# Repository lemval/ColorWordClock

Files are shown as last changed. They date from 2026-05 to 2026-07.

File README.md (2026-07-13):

# Dutch Color clock

Hi,

This is a personal project with lots of effort to get it up and running.
If you have build a clock, please give a little credit to this project. 
This will be greatly appreciated via [Paypal](https://www.paypal.me/valkyer).

The layout of the clock is Dutch! However, it will be pretty easy to create the clock in any language as long as it fits in text. Design your clockface first before proceeding.

## The clock

This is the first version I've build. It uses an aluminium U-frame to hold all layers together. Wood (milled) is easier to work with. It also still uses a DC power connector. Later models are equiped with a USB C connector.

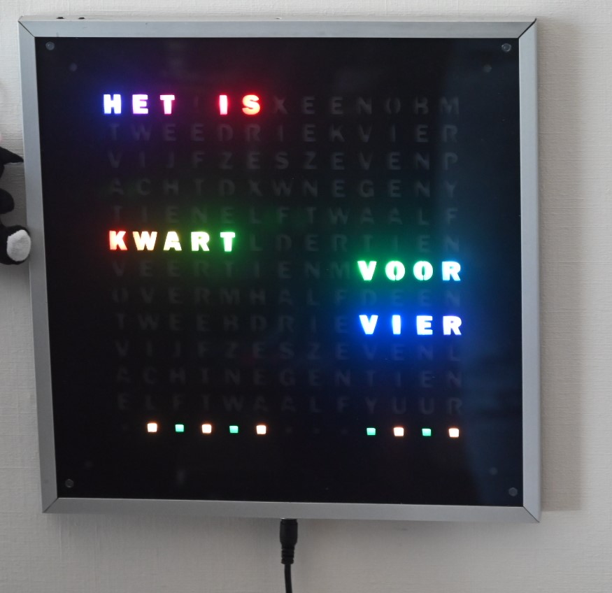
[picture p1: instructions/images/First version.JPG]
First version The first clock


All configurations can be done via the website on the clock.

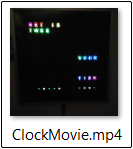
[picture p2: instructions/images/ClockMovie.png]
Check the movie
!

### Faces

1. Warm (text is warm white)
1. Custom (text is a custom color)
1. Rainbow (text uses a rainbow spectrum as seen in the picture above)
1. Animate (same, but slowly shifting)
1. ColorWord (each word another color)
1. ColorChar (each character another color)

### Ticking

The ticking is in a color of your own choice, lightning each corners per 15 seconds, with the following options:
1. Switched off
1. Blink each second
1. Burning solid
1. Fade from solid to off

### Transitions

1. None (no transition)
1. Random (each minute a random pick of transition)
1. Animate (each minute a random FastLED pattern)
1. Flow down (characters fall down...)
1. Fade (text fades out and in)
1. Swipe (remove and reappear by swipe from bottom to top and back)
1. Scanner (same, but starting from right)
1. Spiral (FastLED spiral)
1. Fire (FastLED fire)
1. Rings (FastLED rings)
1. Wave (FastLED waves)
1. Mill (FastLED rotating like a mill)

You have the option to set the duration and animation speed.

### Status bar

The status bar is by default the date in binary. You have the option for some fixed patterns or use the 13 LEDs as status fields from Home Assistant. I tend to like having the date displayed.

## Hardware

Besides some small stuff, you need the following as mentioned below. Costs will be between 50 and 100 euro on material.

Instructions for building the clock are found in the [instruction folder](instructions/Readme.md).

### Board

The clock can fit a model esp32-c6 devkit, which is easy to use and to connect, although the devkit is larger in size.
 
You need at least a 4MB card, however it has only be tested on a 8MB and 16MB card. If you skip OTA capability (you then have to disassemble the clock to update!) you can use a 2MB card.

### Light sensor

Use a model 5516 in combination with a 4K7 resistor.

### LED strip
You need 173 leds (13 x 13 + 4) on a 60D RGB strip, totaling to 3 meter. Use model HD107HD/APA107 (60 leds per meter) or alike, but make sure you can cut each LED individually. Using another model means also changing led_array.h (at FastLED.addLeds).

FastLED supports the SK6812 WWA version for warm/cold white. The upcoming release uses SK6812WWA (alias to SK6812Controller). See [FastLED/FastLED#2347](https://github.com/FastLED/FastLED/pull/2347). I currently have no knowledge if the software will run nicely using such strip.

### Power adapter
A 5 volt power adapter (preferrably USB C but other connectors work) able to deliver at least 30W (6A) but preferrably 45W (9A).

### Power connector

The design is configured for a 20 x 14 x 6.5 mm inlet. See for example [here](https://nl.aliexpress.com/item/1005009400273099.html).

### Materials

Note: you need a laser cutter or have access to one!
All layers should measure at least 30cm x 30cm square

* Ground layer: 6 mm basewood (or alike)
* LED layer: 2 mm MDF
* Control layer: 6 mm MDF (or basewood)
* Diffusion layer: A4 size tracing paper
* Text layer: 0.5mm Lasersheet
* Front layer: 3 mm Tinted grey transparent polycarbonate (or alike)
* Frame: Your choice

I created frames from wood (milled) and alu (U-profile). Be creative.
Be careful to not glue the front and text layer. It will show.

## Software

Create a `settings.h` based on `settings.h.template`. You can show a 'happy birthday' on given dates as transition.

Create a `platformio-local.ini` in the same manner. This allows for using your own password for OTA updates.

Change to your board size in `platformio.ini` by using one of the preconfigured board size config files (set to 16MB standard).

Compile, run and upload using Visual Studio Code with PlatformIO as plugin.

When started, connect to Wifi network 'Clock' and navigate to 192.168.4.1 to configure the Clock for first use. After that, reconnect to a regular Wifi network and open the browser on the assigned IP address.

Once your clock is closed up (assembled) you can only update via OTA.

## Pin layout

* 04 Settings - select (connect other side to GND)
* 05 Settings - next (connect other side to GND)
* 06 Light sensor (3.3V - LDR - SENSOR - 4K7 - GND)
* 19 LED strip - clock
* 20 LED strip - data

## Control

The settings buttons will allow you to configure the clock on a basic level. To configure on a finer level, just open the browser to the clock (not very reactive, since the clock is working on showing you the time and transitions) or use the Home Assistant integration (just configure MQTT via the browser, run a MQTT server and let Home Assistant read from that server).

### Configuration

Press SELECT once to enter settings mode. Press NEXT to cycle through the options of the setting or press SELECT again for the next setting or for closing the settings mode.

Settings are:
1. Change clockface
1. Change transition
1. Activate or disable light sensor
1. Activate or disable seconds
1. Set transition time 

Active = white, disabled = blue.

### Reset

Press NEXT, followed by SELECT. Lower left LED will turn green. Keep pressed and the LED will turn orange. When it turns red after 5 seconds, the clock and network will reset. You have to reconnect to the AP 'Clock' after that.

### Startup

At startup, at the right bottom, red, blue and green will show. As soon as the wifi is connected the red will disappear. As soon as Home Assistant integration and the configuation server is started, blue will switch off. If the clock as been fully initialized, green will follow.

So, when all three colors keep on showing, either the wifi connection fails or the wifi connnection is not configured. The clock should then act as an access point named 'Clock'. Connect to the network and open a browser to the clock its IP address (likely: 192.168.4.1) and configure it.

## Attributes

The following components or libraries are used:

* [WiFiManager by tzapu](https://github.com/tzapu/WiFiManager) (MIT license)
* [home-assistant-integration by dawidchyrzynski](https://github.com/dawidchyrzynski/arduino-home-assistant) (AGPL-3.0 license)
* [NTPClient by arduino-libraries](https://github.com/arduino-libraries/NTPClient) (MIT license)
* [TimeZone by jchristensen](https://github.com/JChristensen/Timezone) (GPL-3.0 license)
* [GoogleTest by Google](https://github.com/google/googletest) (BSD-3-Clause license)
* [FastLED by fastled](https://github.com/FastLED/FastLED) (MIT license)
* [Visual Studio Code](https://code.visualstudio.com/) for coding
* [PlatformIO](https://platformio.org/) for ESP support
* [OpenSCAD](https://openscad.org/) for designing the clock layout
* [LaserGRBL](https://lasergrbl.com/) for burning the layout
* [Cliche](https://www.1001fonts.com/cliche-font.html) for the clock text

## Releases

* Jun 18, 2026 - Version 1.1.0 - Public release

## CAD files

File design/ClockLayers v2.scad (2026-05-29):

// Copyright (c) 2026 - Lemval

clockSize = 300;     // How large is the clock (square)
step = 16.6667;      // The length between each LED center
dotsPerLine = 13;    // Number of LEDs per line 
dotMargin = 27;      // Distance dots from side
lineSize = 12;       // Width of the LED strip
dotSize = 5;         // Size of the LED dot
leader = 12.5;       // Space left and right for soldering
screwSize = 3.25;    // M3 with some slack
resCircle = 15;      // Smoothen circles 
resText = 50;        // Smoothen text
screwOffset = 14.5;  // Location of the corner screws
deviceWidth = 54;    // Width of the ESP
deviceHeight = 32;   // Height of the ESP
deviceThickness = 7; // Thickness of the ESP

// Glueing magnets to the front plate requires non-invasive glue!
// magnetSize = 5.1;
// magnetOffset = 20;

// If you use another layout (other language), make sure you work the code.
letters="HET!ISXEENOBMTWEEDRIEKVIERVIJFZESZEVENPACHTDXWNEGENYTIENELFTWAALFKWARTLDERTIENVEERTIENMVOOROVERMHALFDEENTWEEBDRIEVIERVIJFZESZEVENLACHTNEGENTIENELFTWAALFYUUR▪▪▪▪▪▪▪▪▪▪▪▪▪";
fontSize=12;
fontName="Cliche:style=regular";

// There are different layers to cut. Generate or use existing ones.
// The power line uses a USB C socket. Change the model for other sockets.
// Speed/power/passes are based on a 20W diode laser.

// printGroundLayer();   // Basewood 6 mm - 300mm/m, 100%, 2 passes
// printEngraveLayer();  // On ground layer - 3000mm/m, 20%, 1 pass
// printLedStripLayer(); // MDF 2 mm - 400mm/m, 100%, 1 pass
// printControlLayer();  // MDF 6 mm - 300mm/m, 100%, 3 passes
// printTextLayer();     // Lasersheet 0.5mm - 600mm/m, 90%, 1 pass

module printGroundLayer() {
    difference() {
        square(clockSize);
        Screws();
    }
}

module printEngraveLayer() {
    // This layer can be used for aligning LEDs on LED layer
    width=0.1;
    // Center line
    translate([clockSize/2, clockSize/2, 0]) square([width, clockSize], center=true);
    // Dot lines, left vertical
    translate([dotMargin, clockSize/2, 0]) square([width, clockSize], center=true);
    // Dot lines, right vertical
    translate([clockSize-dotMargin, clockSize/2, 0]) square([width, clockSize], center=true);
    // Dot lines, top horizontal
    translate([clockSize/2, clockSize-dotMargin, 0]) square([clockSize, width], center=true);
    // Dot lines, bottom horizontal
    translate([clockSize/2, dotMargin, 0]) square([clockSize, width], center=true);
    translate([dotMargin+5, 12, 0]) text("(c) 2026 Lemval", font=fontName, size=6, $fn=50);      
}

module printLedStripLayer() {
    // Carved for strips and wiring
    difference() {
        square(clockSize);
        union() {
            for(idx = [0 : 1 : dotsPerLine-1]) 
                StripLed(idx, false);
            Screws();
            Device();
            DotWires();
            PowerConnector();
        }
    }
}

module printControlLayer() {
    // Carved for device and light boxes
    // mirror([180,0,0]) 
    difference() {
        square(clockSize);
        union() {
            // Add the text squares
            for(idx = [0 : 1 : dotsPerLine-1]) 
                Text(idx, true);
            Screws();
            Device();
            LightSensor();
            Switches();
            PowerInlet();
            Dots(true);   
            // Magnets(); 
        }
    }
}

module printTextLayer() {
    // Carved for text
    difference() {
        square(clockSize);
        union() {
             Dots(false);     
             for(idx = [0 : 1 : dotsPerLine-1]) Text(idx, false);
            // Magnets(); 
            // Bolts();
        }
    }
}

module Device() {
    translate([44, clockSize-39, 0]) 
        square([deviceWidth+20,deviceHeight]);
}

module LightSensor() {
    // Space on top. Drill when needed for wires
    translate([clockSize/2, clockSize-1, 0]) 
        square([4.2,2], true);
    // Vertical portal
    translate([clockSize/2, clockSize-18, 0]) 
        square([4,20], true);
    // Horizontal portal
    translate([45+deviceWidth, clockSize-31, 0]) 
        square([clockSize/2-45-deviceWidth+2,4]);
}

module PowerConnector() {
    // Conduit
    translate([clockSize/2, 15]) square([10, 20], true);
    // Extra wire space
    translate([clockSize/2, 18]) square([18, 9], true);
}

module PowerInlet() {
    translate([clockSize/2-10, 0]) square([20, 2.5]);
    translate([clockSize/2, 10]) square([10, 20], true);
}

module Switches() {
    // Small holes should be drilled from the side.
    offset = 17;
    // Switch 1
    translate([offset, clockSize-15,0]) square([7,10], false);
    // Switch 2
    translate([offset+13, clockSize-15,0]) square([7,10], false);
    // Switch wire
    translate([offset, clockSize-17,0]) square([28,3], false);
}

module StripLed(row, showDots) {
    length = leader + dotsPerLine * step;
    height = dotsPerLine * step - (lineSize/2);
    startX = (clockSize - length) / 2;
    startY = (clockSize - height) / 2;
    yPos = startY + row * step;
    
    translate([startX, yPos, 0]) square([length, lineSize]);
    
    if (showDots) {    
        yStart = yPos + lineSize/2;
        xStart = (clockSize - dotsPerLine * step + leader + dotSize)/2;
        for(idx = [0 : 1 : dotsPerLine - 1]) {
           translate([xStart + idx * step, yStart, 0]) square(dotSize, true);
        }
    }
    
    drawWireSpace(startX, yPos, row%2 == 0);
}

module drawWireSpace(x, y, isEven) {
    startX = isEven ? x - 7 : x + dotsPerLine * step + 3;
    translate([startX,y,0]) square([step, step+lineSize]);
}

module Text(row, showBlocks) {
    base = (clockSize - dotsPerLine * step) / 2;
    startX = base + (leader + dotSize)/2;
    startY = base + (lineSize + dotSize)/2 + 0.5 + (dotsPerLine-1-row) * step;
    
    for(idx = [0 : 1 : dotsPerLine-1]) {
        character = letters[idx + dotsPerLine * row];
        translate([startX + idx * step, startY, 0]) {
            if (showBlocks) {
                sSize = fontSize+1;
                square(sSize, true);
            } else {
                text(character, 
                     size=fontSize,
                     font=fontName,
                     halign="center",
                     valign="center",
                     $fn=50);
            }      
        }
    }
}

module DotWires() {
    max = clockSize - dotMargin;
    min = dotMargin;
    width = lineSize + 18;
    height = lineSize + 2;
    spacer = 20;
    length = max - min - 2*spacer;

    // Boxes for the dot elements
    translate([min+2, max-1, 0]) square([width, height],true);
    translate([max-2, max-1, 0]) square([width, height],true);
    translate([max-2, min+1, 0]) square([width, height],true);
    translate([min+2, min+1, 0]) square([width, height],true);
    
    // Bottom wire section
    translate([min+10, min-6, 0]) square([length+20, 7]);
    // Top wire section
    translate([min+10, max-1, 0]) square([length+20, 7]);
    // Left wire section
    translate([min-13, min+spacer-8, 0]) square([7, length+15]);
    
    drawWireSpace(max-11, min+1, true);
}

module Dots(blocks) {
    max = clockSize - dotMargin;
    min = dotMargin;
    translate([min, max, 0]) 
        if (blocks) square(fontSize+1, true); else circle(3,true, $fn=20);
    translate([max, max, 0])
        if (blocks) square(fontSize+1, true); else circle(3,true, $fn=20);
    translate([max, min, 0])
        if (blocks) square(fontSize+1, true); else circle(3,true, $fn=20);
    translate([min, min, 0])
        if (blocks) square(fontSize+1, true); else circle(3,true, $fn=20);
}

module Screws() {
    max = clockSize - screwOffset;
    min = screwOffset;
    delta = 20;
    xLeft = clockSize/2-delta;
    xRight = clockSize/2+delta;
    translate([min, max, 0]) circle(d=screwSize, $fn=resCircle);
    translate([max, max, 0]) circle(d=screwSize, $fn=resCircle);
    translate([max, min, 0]) circle(d=screwSize, $fn=resCircle);
    translate([min, min, 0]) circle(d=screwSize, $fn=resCircle);
    
    translate([clockSize/2, 30, 0]) circle(d=screwSize, $fn=resCircle);
    translate([xLeft, max, 0]) circle(d=screwSize, $fn=resCircle);
    translate([xRight, max, 0]) circle(d=screwSize, $fn=resCircle);
}

module Magnets() {
    space = clockSize/4;
    left = magnetOffset;
    right = clockSize - magnetOffset;
    bottom = left;
    top = right;
    p1 = space;
    p3 = 3*space;
    
    translate([left, p3, 0]) circle(d=magnetSize, $fn=resCircle);
    translate([left, p1, 0]) circle(d=magnetSize, $fn=resCircle);
    translate([right, p3, 0]) circle(d=magnetSize, $fn=resCircle);
    translate([right, p1, 0]) circle(d=magnetSize, $fn=resCircle);
    translate([p1, top, 0]) circle(d=magnetSize, $fn=resCircle);
    translate([p3, top, 0]) circle(d=magnetSize, $fn=resCircle);
    translate([p1, bottom, 0]) circle(d=magnetSize, $fn=resCircle);
    translate([p3, bottom, 0]) circle(d=magnetSize, $fn=resCircle);
}
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

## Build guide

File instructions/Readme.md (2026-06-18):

# Instructions

Instructions to build the clock.

## Groundwork

Start out with a square [ground layer](../design/ClockLayers%20v2%20layer1%20base6%202x300x100.svg), optionally with holes for small bolts to join the layers. Optionally burn the [guide lines](../design/ClockLayers%20v2%20layer1a%20base6%201x3000x20.svg) on this ground layer to correctly position the LEDs. Glue the [led layer](../design/ClockLayers%20v2%20layer2%20mdf2%201x400x100.svg) atop of it and make sure the lanes are straigh. You can use the cut out part for this, but make sure this part is not glued to the ground layer.

The result is something like this:
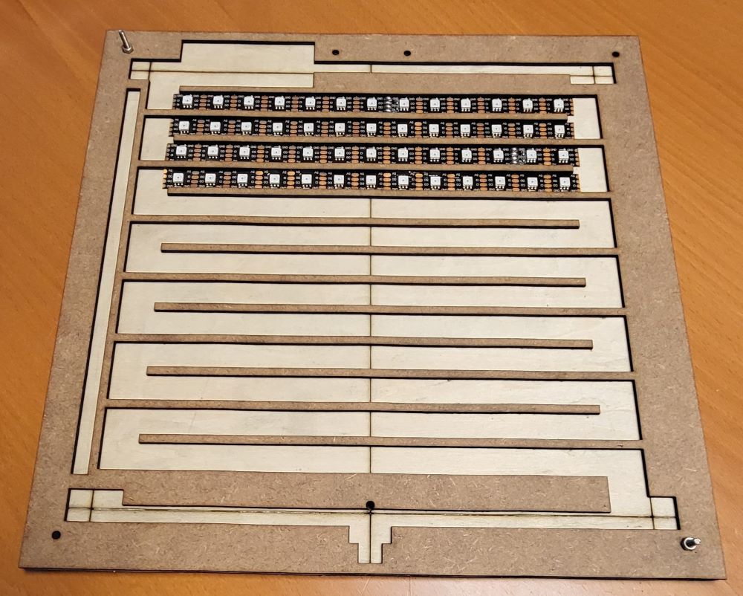
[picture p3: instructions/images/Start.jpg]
Ground and LED layer with LED strip The first step


## Add LEDs

Cut the first section of the strip to form a row (13 LEDs). Always start in the upperleft corner with 'DI' or 'Data In' because that is where the controller will be connected. Remove the protective foil so that the adhesive strip can be used to put it in place. Use the center line to position the center LED. Sometimes the welded part enlarges the distance between LEDs. Either correct the welding or accept a little displacement.

The second section or row will be upside down, because you end with 'data out' which should be connected on the same side to 'data in'.

This hence and forth positioning is called 'serpentine'.

Position the last four LEDs in the corners while taking the direction of the data line into account. The order is: bottom right, bottom left, top left, top right.

The result is something like this:
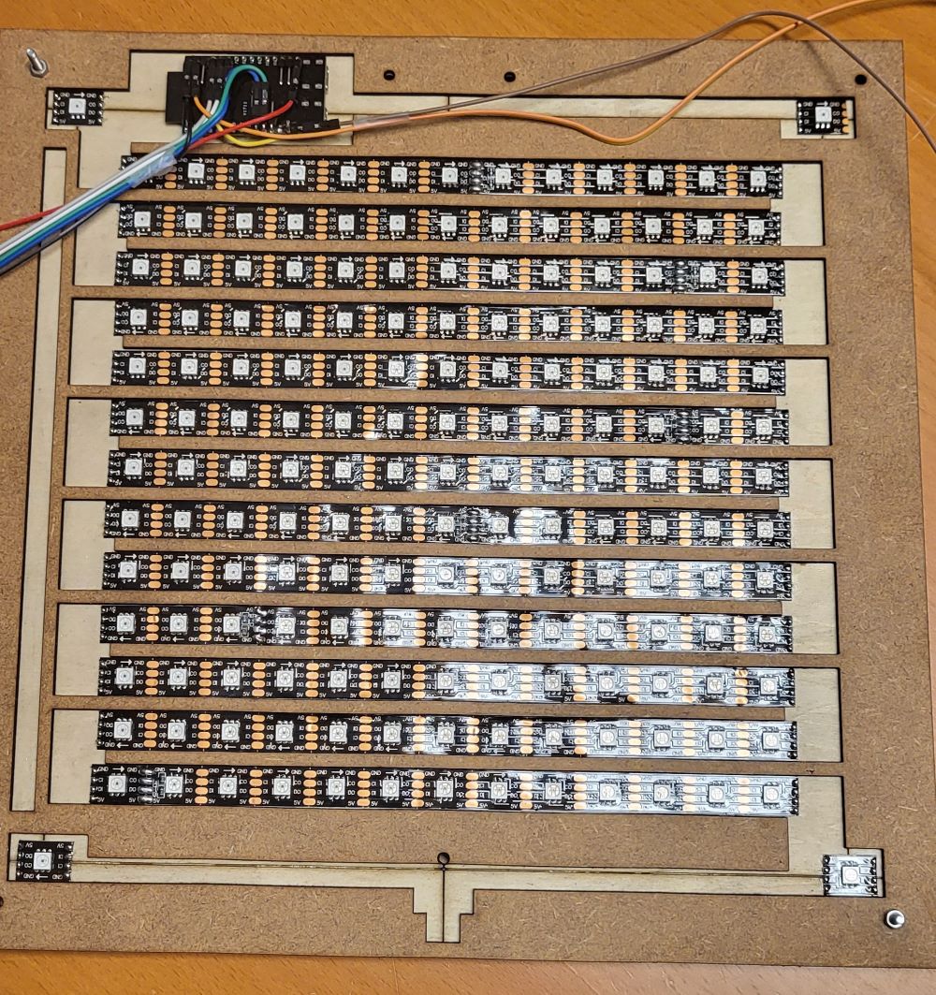
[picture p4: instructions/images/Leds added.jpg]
Ground and LED layer with LED strip The second step


## Wiring and cutting

Cut open the lane on the left side. This allows the wiring for the corner LEDs. Use preferrably different colors for power, ground, data and clock. Solder the corner LEDs like the image below. On the bottom side of the clock you need extra length for power and ground to weld the power connector in place. On the top side make sure the wires need to be placed at the side of the open space, otherwise the ESP won't fit. Glue down these wires to the wood.

Next wire the LED strips ground to ground, power to power, clock out to clock in, data out to data in.

For the ESP I used bended pin headers (male) and wires with pin headers (female). You can optionally directly solder the wires to the ESP. Cut the wires in the right length and attach the LED strips. Do not yet attach the light sensor and switches.

The result is something like this:
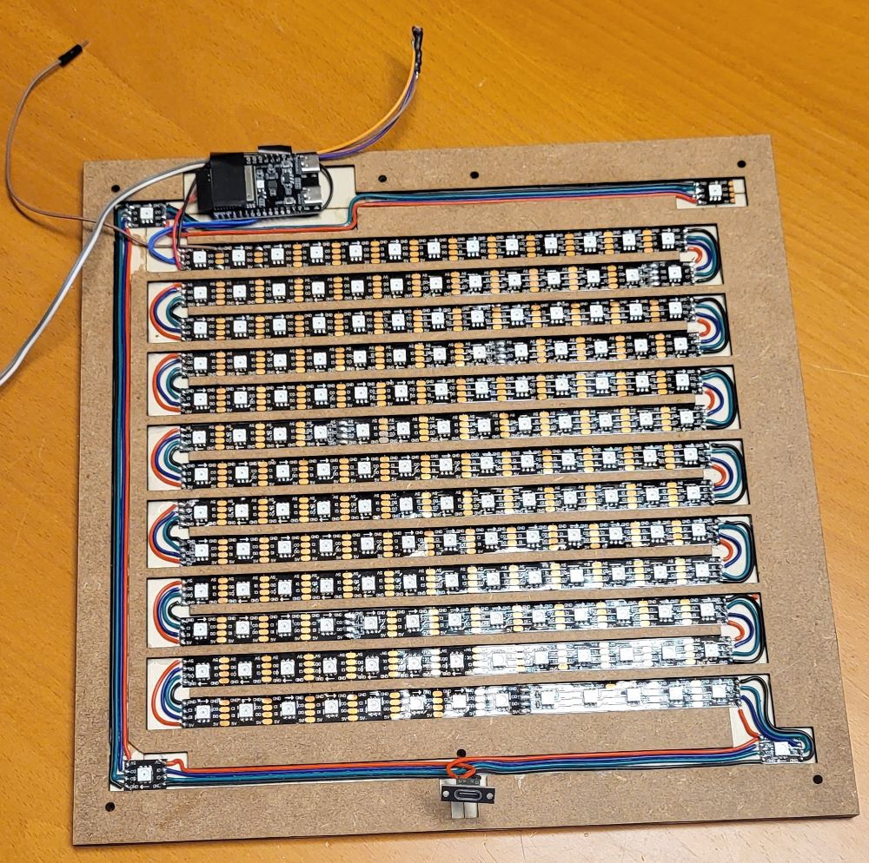
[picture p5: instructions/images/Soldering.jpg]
Wired result The third step


## Connecting the ESP

I use standard bend headers for connecting the ESP in combination with female jumper wires for DIY kits.

Place a header (A) of 6 on GND/3V3/RST/4/5/6.  
Place a header (B) of 2 on 13/5V.  
Place a header (C) of 6 on 5V/GND/9/18/19/20.

Connect a red wire to 5V on C and a black wire to GND on A. This powers the board. Connect the other side of these wires to the LED strip. Make sure you know how to position the board and use lengths accordingly. Initially I had the board flipped over the long side, but this is better for accessibility.

Pin 19 and 20 make up the clock and data. These need also be soldered to the LED strip. Best to use the same colors as used for connecting the parts of the LED strip (green for clock, blue for data).

The light sensor uses header A connected like: `3.3V - LDR - SENSOR - 4K7 - GND`. Orange represents 3V3, purple the data and brown ground. Connect as specified and use shrinking material or tape to isolate.

The yellow wire is connected to the switch for `select` and green for `next`. The switches should be connected to ground on the other terminal. On the picture, this is also a brown wire, which is connected to the LED strip.

Make sure all wires can be nicely placed flat enough for the placement of the control layer.

The layout of your ESP can be found online. For example:
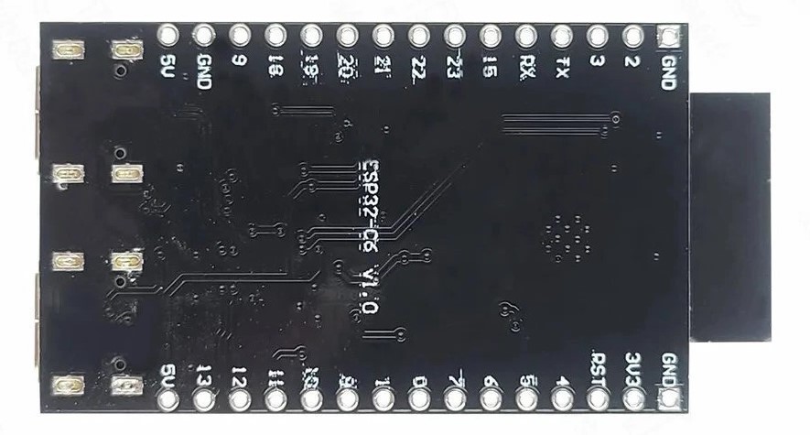
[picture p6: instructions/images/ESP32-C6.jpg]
ESP C6 pinout Credits unknown


The result is something like this:
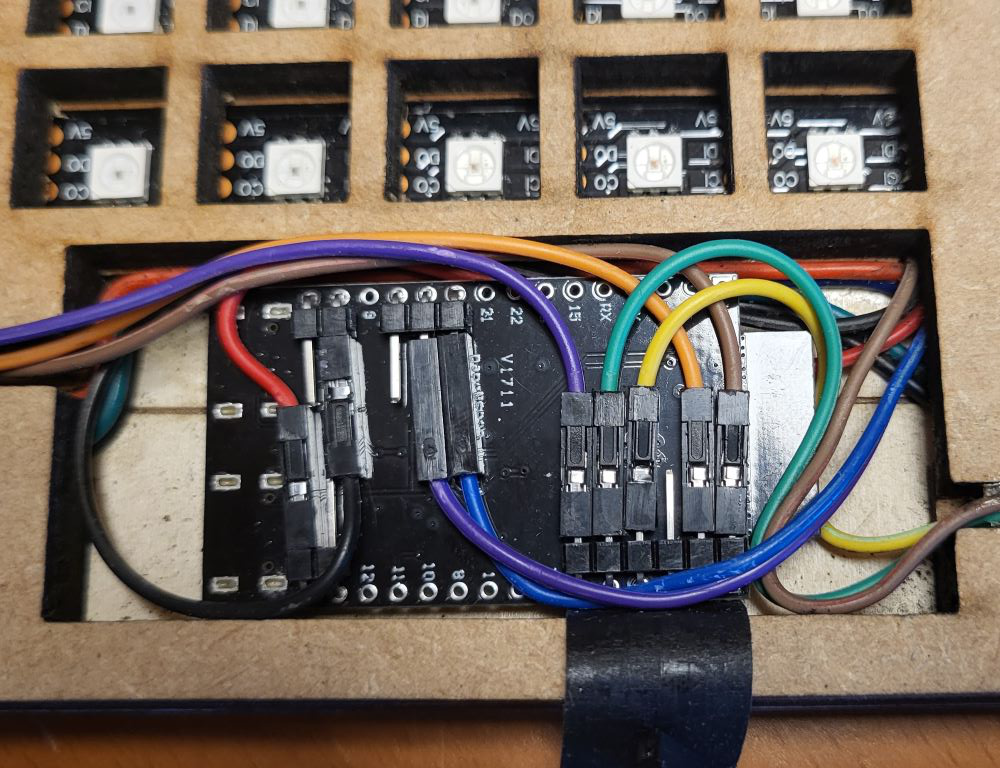
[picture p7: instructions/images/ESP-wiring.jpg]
Connecting ESP The fourth step


## Control layer and front plate

Guide all wires for the ESP, switches and sensor though the large open section and make sure the control layer is placed flat on the LED layer. Fixate the three layers. For example, use bolts and nuts. Make sure the front is flat by sinking the bolt head in the wood. Drill very carefully.

Attach the ESP if you didn't already do that and use tape to make sure the front is flat. This takes some fitting, nudging and tweaking.

Test the clock, make sure it is working.

Optionally add the switches and the light sensor. 

Paint the front plate in the color of your choice. Black is safe and beautiful. Let it dry and lasercut it. Spray-glue the back and attach the tracing paper (this paper diffuses the light, you need it!).

The result is something like this:
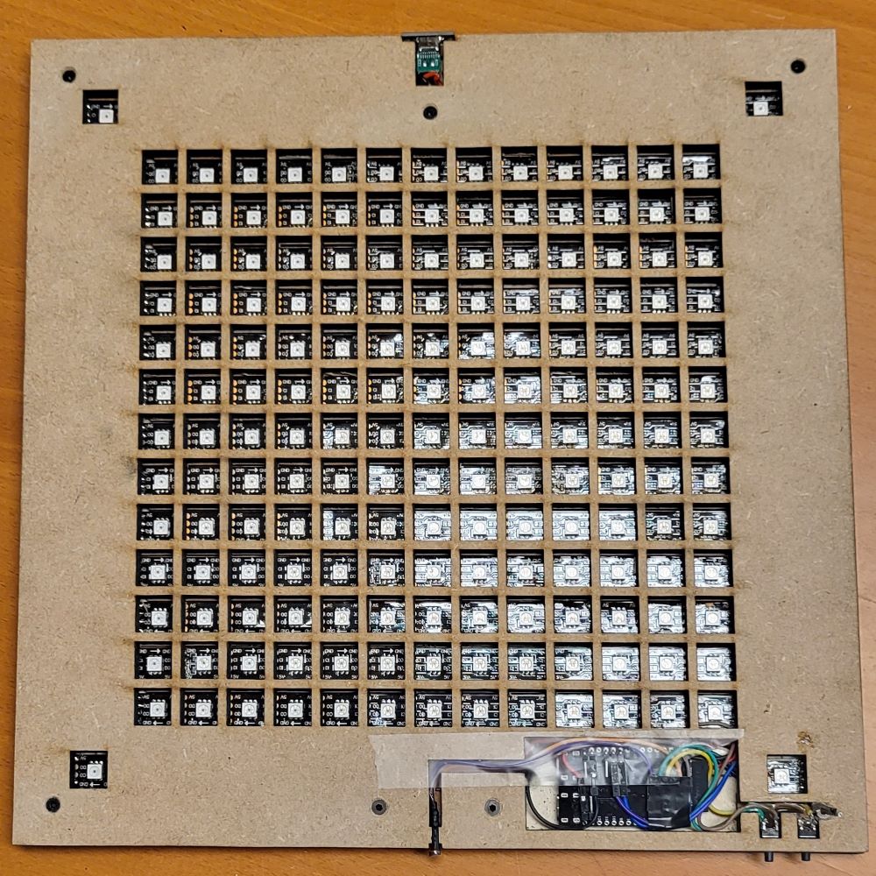
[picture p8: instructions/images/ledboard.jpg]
Control layer attached The fifth step


## Frame

For this you can use a hardwood slat of about 28 by 9 millimeters. A groove is milled using a wood router. This groove should exactly match the thickness of the clock. 

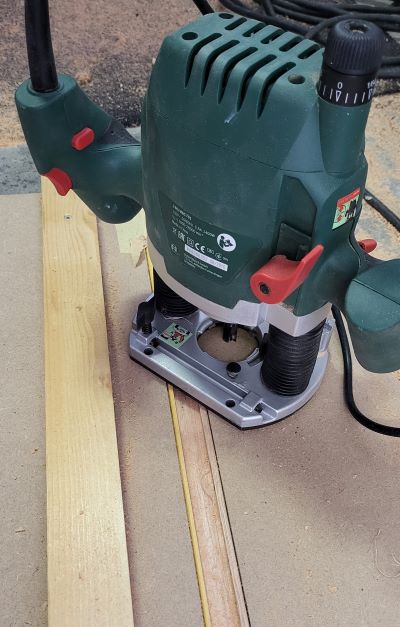
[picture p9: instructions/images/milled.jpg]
Milled slat The sixth step


Use a miter saw or chop saw to make the frame pieces. Apply some slack as you can always make the pieces a little shorter. As my front plate was a little askew, I needed a couple of millimeters extra. Cut out holes for the power plug and the light sensor. Optionally, cut out holes for the switches. Measure and match the pieces and mark them if necessary.

Paint in the color of your liking. Test the clock for a last time. Use wood glue to make the frame. Do not apply glue at the front side. Since the frame does not have to hold any weight, you should not glue the frame to the clock.

Create a hanging hook or create a stand.

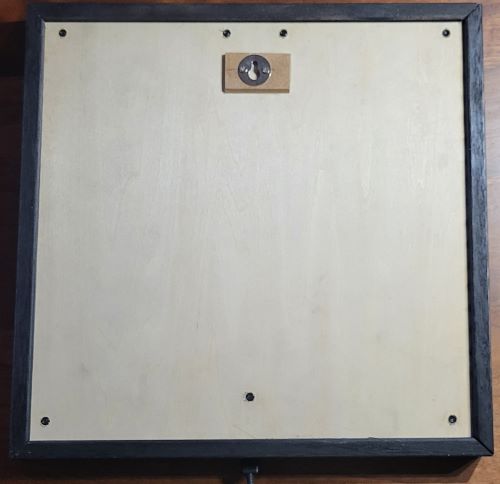
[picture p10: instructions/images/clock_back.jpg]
Hanging hook The seventh step


Done!

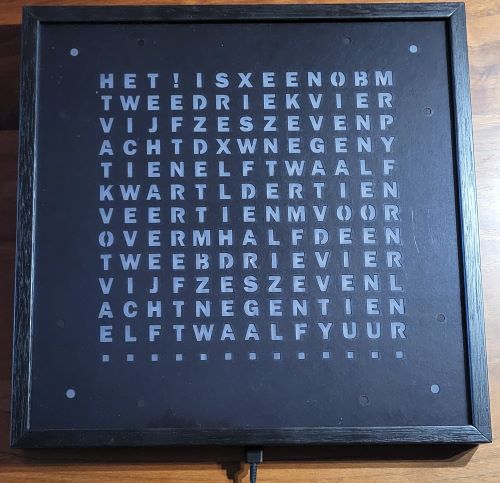
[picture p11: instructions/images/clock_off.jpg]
Ready and off Done 1


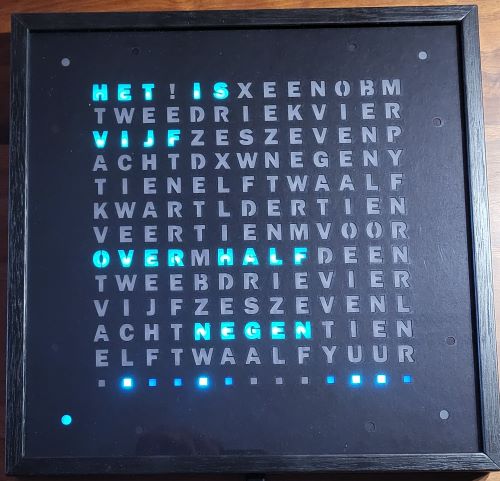
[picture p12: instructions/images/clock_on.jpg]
Ready and on Done 2


<small>Note: The switched off characters are far more visible in the photograph than actually perceived.</small>

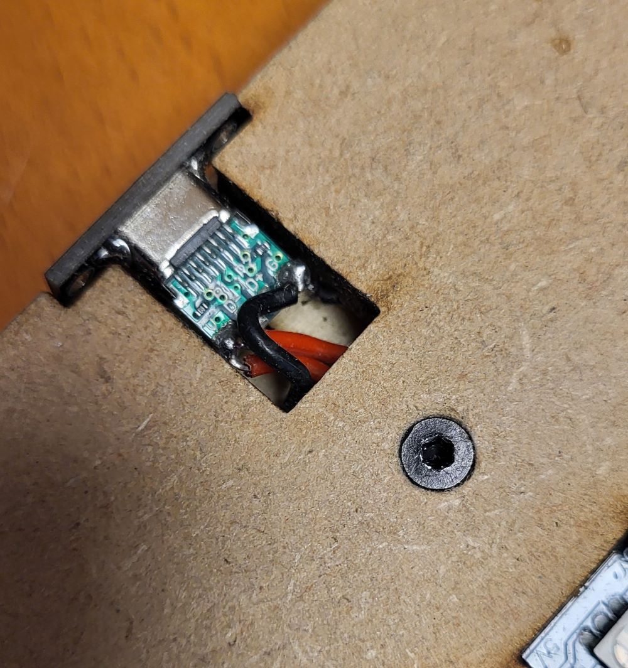
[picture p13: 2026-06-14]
instructions/images/Power connector.jpg

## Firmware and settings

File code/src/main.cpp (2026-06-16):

#include <Arduino.h>
#include <ArduinoOTA.h>
#include <NTPClient.h>

#include "analog_reader.h"
#include "board_led.h"
#include "config_server.h"
#include "ha_settings.h"
#include "settings.h"
#include "switch_control.h"
#include "wifi_connect.h"
#include "word_clock.h"

NetworkUDP udp;
NTPClient ntp = NTPClient(udp);

WordClock wordClock;
ConfigServer configServer(&wordClock);
AnalogReader analog;
SwitchControl control;

// Should span over threads
volatile bool tick = false;

uint32_t last_ota_time = 0;

hw_timer_t* timer = NULL;

void IRAM_ATTR timerTask() { tick = true; }

void setupOTA() {
    ArduinoOTA.setPort(55910);
    ArduinoOTA.setHostname(WiFi.getHostname());
    ArduinoOTA.setPassword(OTA_PASSWORD);
    ArduinoOTA.onStart([]() { Serial.println("[Update] started"); })
        .onEnd([]() { Serial.println("[Update] End"); })
        .onError([](ota_error_t error) { Serial.printf("[Update] Error %d while uploading!\n", error); })
        .onProgress([](unsigned int progress, unsigned int total) {
            if (millis() - last_ota_time > 500) {
                Serial.printf("[Update] Progress: %u%%\n", (progress / (total / 100)));
                last_ota_time = millis();
            }
        });
    ArduinoOTA.begin();
}

void setup() {
    wordClock.initialize();

    setupWifiConfiguredConnection();

    wordClock.setStatusColor(10, 0, 0, 0);

    configServer.startServer();

    ntp.setUpdateInterval(50000 * 60 * 5);
    ntp.begin();

    setupHomeAssist(&wordClock, &configServer);

    wordClock.setStatusColor(11, 0, 0, 0);

    control.setup(&wordClock);

    setupOTA();

    timer = timerBegin(1000000);  //  1Mhz resolution timer
    timerAttachInterrupt(timer, &timerTask);
    timerAlarm(timer, 1000 * 1000, true, 0);  // Each second an alarm

    wordClock.setStatusColor(12, 0, 0, 0);
    Serial.println("Clock started!");
}

void updateLightLevel() {
    if (!wordClock.getLightSensorState()) return;

    analog.read();
    int percentage = analog.getPercentage() * 1;  // TODO
    wordClock.updateBrightness(percentage);
    updateAnalog(percentage);
}

void loop() {
    ArduinoOTA.handle();
    control.loop();
    loopMqtt();

    if (tick) {
        tick = false;
        ntp.update();

        if (ntp.isTimeSet()) {
            Timezone tz = configServer.getTimeZone();
            long now = tz.toLocal(ntp.getEpochTime());
            configServer.setStartTime(now);
            wordClock.update(now);
        }

        updateLightLevel();
        updateIP(WiFi.localIP().toString().c_str());
    }

    configServer.handleRequests();
    wordClock.animate();

    // Do not delay here as this is blocking HA to work correctly.
}

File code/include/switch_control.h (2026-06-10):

#ifndef SWITCH_CONTROL_h
#define SWITCH_CONTROL_h

#include <Arduino.h>

#include "wifi_connect.h"
#include "word_clock.h"

#define PIN_SELECT 4
#define PIN_NEXT 5

#define DEBOUNCE_TIME 50
#define SETTINGS_COUNT 5

class SwitchControl {
   private:
    WordClock* clockRef = NULL;
    CRGB passive = CRGB::DarkRed;
    CRGB active = CRGB::DarkGreen;
    CRGB s[SETTINGS_COUNT] = {passive, passive, passive, passive, passive};
    bool shown;
    bool settingsActive = false;
    bool resetActive = false;
    int8_t brightness = 125;

    // CRGB settingsMap[FACE_LEDS];
    // uint8_t settingsIndex = 0;

   public:
    SwitchControl() {
        // config input pins and enable the internal pull-up resistor
        // Switches connect to GROUND! Normally OPEN means HIGH.

        pinMode(PIN_SELECT, INPUT_PULLUP);
        pinMode(PIN_NEXT, INPUT_PULLUP);
    }

    void setup(WordClock* clock) { clockRef = clock; }

    void loop() {
        if (settingsActive == false && digitalRead(PIN_NEXT) == LOW) {
            resetActive = true;

            brightness = FastLED.getBrightness();
            FastLED.setBrightness(255);
            clockRef->setVisible(false);
            shown = false;
            clockRef->markIndication(0, CRGB::Green2);
            FastLED.show();

            delay(2000);
            if (digitalRead(PIN_NEXT) == LOW && digitalRead(PIN_SELECT) == LOW) {
                clockRef->markIndication(0, CRGB::Orange2);
                FastLED.show();
                delay(3000);
                if (digitalRead(PIN_NEXT) == LOW && digitalRead(PIN_SELECT) == LOW) {
                    clockRef->markIndication(0, CRGB::Red2);
                    FastLED.show();
                    wifiReset();
                    clockRef->resetSettings();
                    resetActive = false;
                    ESP.restart();
                } else
                    resetActive = false;
            } else
                resetActive = false;

            if (resetActive == false) {
                FastLED.setBrightness(brightness);
                clockRef->setVisible(true);
            }
        }

        if (resetActive == false && digitalRead(PIN_SELECT) == LOW) {
            settingsActive = true;
            // Settings mode is entered
            brightness = FastLED.getBrightness();
            FastLED.setBrightness(255);
            clockRef->setVisible(false);
            shown = false;

            size_t index = 0;
            while (index < SETTINGS_COUNT) index = readSetting(index);

            // Settings are set, now update
            updateSettings(FlowOption(clockRef->getFlowOption()),  //
                           FaceOption(clockRef->getFaceOption()),  //
                           clockRef->getTickOption(),              //
                           clockRef->getLightSensorState(),        //
                           clockRef->getFlowTime());

            settingsActive = false;
            FastLED.setBrightness(brightness);
            clockRef->setVisible(true);
        }
    }

   private:
    void clearMarkings() {
        for (size_t i = 0; i < kMatrixWidth; i++) clockRef->markIndication(i, CRGB::Black);
        FastLED.show();
    }

    void updateLightSensor() {
        clockRef->markIndication(7, clockRef->getLightSensorState() ? CRGB::White : CRGB::DarkBlue);  // TWAA_L_F
        FastLED.show();
    }

    void updateTickSensor() {
        CRGB color = CRGB::White;
        switch (clockRef->getTickOption()) {
            case TickOption::Off:
                color = CRGB::Blue4;
                break;
            case TickOption::Solid:
                color = CRGB::Yellow4;
                break;
            case TickOption::Blink:
                color = CRGB::White;
                break;
            case TickOption::Fade:
                color = CRGB::Green4;
                break;
        }
        clockRef->markIndication(3, color);  // _T_WAALF
        FastLED.show();
    }

    void updateFlowTime() {
        int currentTime = clockRef->getFlowTime();
        // 13 positions, for time between 250 and 3000
        int pos = max(0, ((currentTime / 250) - 1) % kMatrixWidth);
        if (pos >= kMatrixWidth) pos = 0;

        clearMarkings();
        clockRef->markIndication(pos, CRGB::White);
        FastLED.show();
    }

    /*
    void showHue() {
        CHSV customColor = rgb2hsv_approximate(clockRef->getCustomColor());
        uint8_t sat = customColor.sat;
        uint8_t val = customColor.val;
        uint8_t current = customColor.hue;
        uint8_t delta = 255;

        for (size_t i = 0; i < FACE_LEDS; i++) {
            uint8_t hue = map(i, 0, FACE_LEDS - 1, 0, 255);
            settingsMap[i] = CRGB(CHSV(hue, sat, val));
            uint8_t diff = abs(current - hue);
            if (diff < delta) {
                delta = diff;
                settingsIndex = i;
            }
        }
        Serial.printf("Set hue index to %d (diff = %d)\n", settingsIndex, delta);
        clockRef->showMap(settingsMap, FACE_LEDS, settingsIndex);
    }

    void showSaturation() {
        CHSV customColor = rgb2hsv_approximate(clockRef->getCustomColor());
        uint8_t current = customColor.sat;
        uint8_t val = customColor.val;
        uint8_t hue = customColor.hue;
        uint8_t delta = 255;

        for (size_t i = 0; i < FACE_LEDS; i++) {
            uint8_t sat = map(i, 0, FACE_LEDS - 1, 0, 255);
            settingsMap[i] = CRGB(CHSV(hue, sat, val));
            uint8_t diff = abs(current - sat);
            if (diff < delta) {
                delta = diff;
                settingsIndex = i;
            }
        }
        Serial.printf("Set sat index to %d (diff = %d)\n", settingsIndex, delta);
        clockRef->showMap(settingsMap, FACE_LEDS, settingsIndex);
    }

    void showValue() {
        CHSV customColor = rgb2hsv_approximate(clockRef->getCustomColor());
        uint8_t sat = customColor.sat;
        uint8_t current = customColor.val;
        uint8_t hue = customColor.hue;
        uint8_t delta = 255;

        for (size_t i = 0; i < FACE_LEDS; i++) {
            uint8_t val = map(i, 0, FACE_LEDS - 1, 0, 255);
            settingsMap[i] = CRGB(CHSV(hue, sat, val));
            uint8_t diff = abs(current - val);
            if (diff < delta) {
                delta = diff;
                settingsIndex = i;
            }
        }
        Serial.printf("Set val index to %d (diff = %d)\n", settingsIndex, delta);
        clockRef->showMap(settingsMap, FACE_LEDS, settingsIndex);
    }

    CRGB nextColor() {
        settingsIndex = (settingsIndex + 1) % 256;
        return settingsMap[settingsIndex];
    }
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

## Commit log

2026-05-29 Design added
    [ClockLayers v2.scad]
2026-05-29 Format pin layout list in README.md
    Updated pin layout section for clarity and formatting.
2026-06-10 Add light sensor inverted (wrongly connected) to settings.
    [analog_reader.h]
2026-06-14 Frame description, resize photos
